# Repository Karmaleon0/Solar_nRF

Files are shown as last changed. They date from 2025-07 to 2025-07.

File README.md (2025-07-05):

A small solar-only, battery-free device that harvests energy using a single BPW34 cell, boosted and managing energy with the TI B5504.

B5504

Sending BLE advertisements every few seconds in direct sunlight - measuring the temperature using an exteral I2C digital chip connected to a Raytac nRF module.

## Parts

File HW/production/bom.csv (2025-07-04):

Designator | Footprint | Quantity | Value | LCSC Part #
C1, C2 | 0805 | 2 | 4.7u
C12, C13 | 0603 | 2 | 12p
C14 | 0805 | 1 | 100n
C3 | 0603 | 1 | 10n
C4, C6, C7, C8, C9 | 1206 | 5 | 100u
C5 | 1206 | 1 | 100uF
D1 | D_SOD-123F | 1 | 3V8
D11 | 0805 | 1 | LED
J10, J11, J4, J5 | PinSocket_1x02_P2.54mm_Vertical | 4 | Conn_01x02
J13 | PinHeader_2x03_P2.54mm_Vertical | 1 | Conn_02x03_Odd_Even
J2, J6, J7 | PinHeader_1x04_P2.54mm_Vertical | 3 | Conn_01x04
L2 | WE-TPC_2828 | 1 | WE-TPC_2828
Q1, Q2 | SOT-23 | 2 | IRLML6402
R1, R2, R4 | 0603 | 3 | R
R3, R6 | 0603 | 2 | 0R
R5, R7 | 0603 | 2 | 1M
R8 | 0805 | 1 | R
ROK_2 | 0603 | 1 | 6.49M
ROK_3 | 0603 | 1 | 6.0M
ROV_1 | 0603 | 1 | 3.16M
RUV_2 | 0603 | 1 | 1.78M
R_OC1 | 0603 | 1 | 4.99M
R_OC2 | 0603 | 1 | 15M
R_OK1 | 0603 | 1 | 3.4M
R_OV2 | 0603 | 1 | 6.19M
R_UV1 | 0603 | 1 | 4.87M
SC1 | CAPPRD508W154D1200H850 | 1 | 100mF
TC1, TC2 | TC2030-IDC | 2 | TC2030-IDC
TP1 | TestPoint_Pad_D1.0mm | 1 | TestPoint
U1 | VQFN-16-1EP_3x3mm_P0.5mm_EP1.68x1.68mm | 1 | BQ25504
U2 | SOIC-8_3.9x4.9mm_P1.27mm | 1 | ATtiny402-SS
U3 | MDBT42TV-P | 1 | MDBT42TV
U4 | SOT-563 | 1 | TMP112xxDRL
Y1 | XTAL_ABS07-32.768KHZ-T | 1 | ABS07-32.768KHZ-T

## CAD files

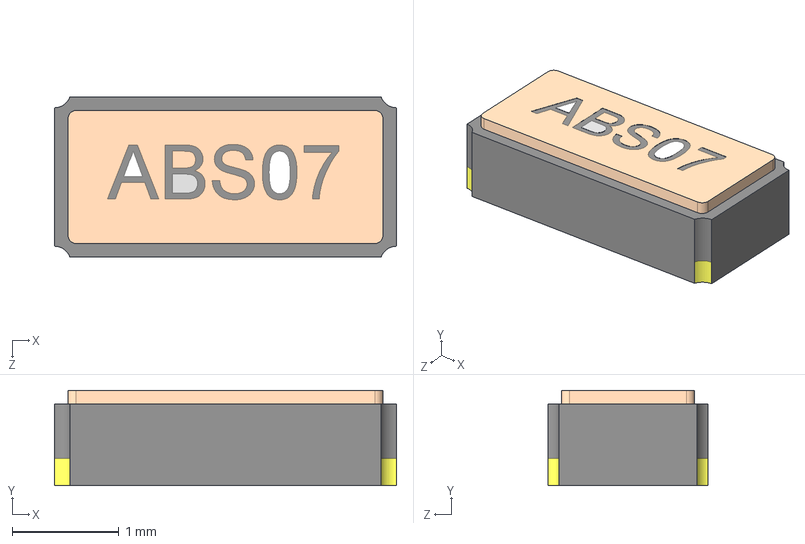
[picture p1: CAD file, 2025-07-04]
HW/Components/ABS07-32.768KHZ-T/ABS07-32.768KHZ-T.step
3.20 x 0.889 x 1.50 mm

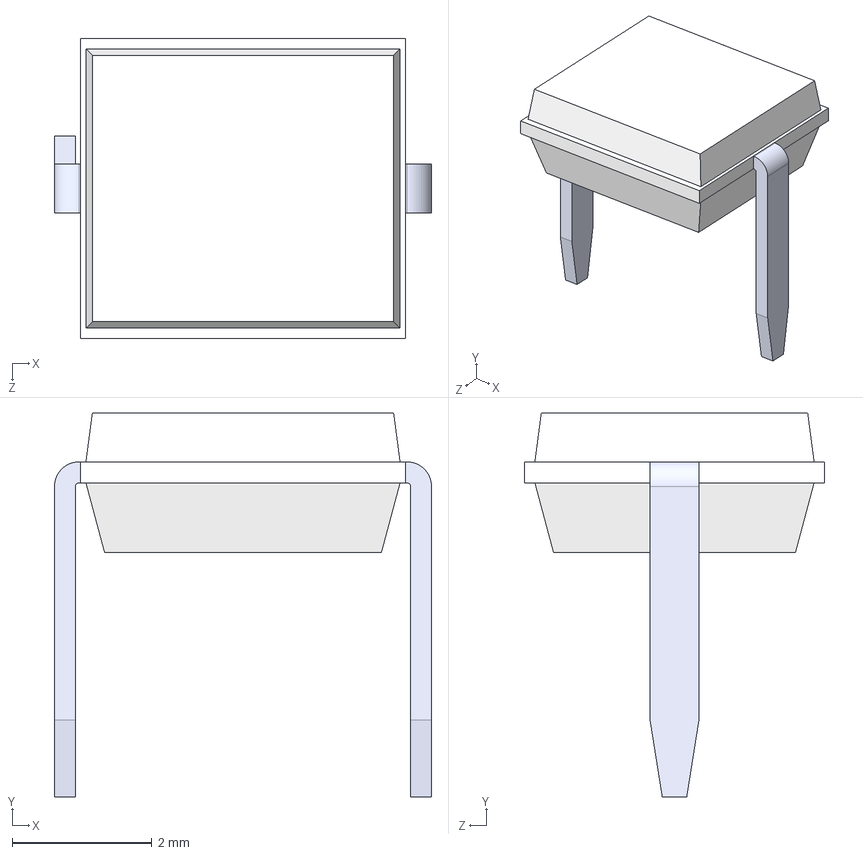
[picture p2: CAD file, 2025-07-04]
HW/Components/BPW34/BPW34--3DModel-STEP-56544.STEP
5.40 x 5.50 x 4.30 mm

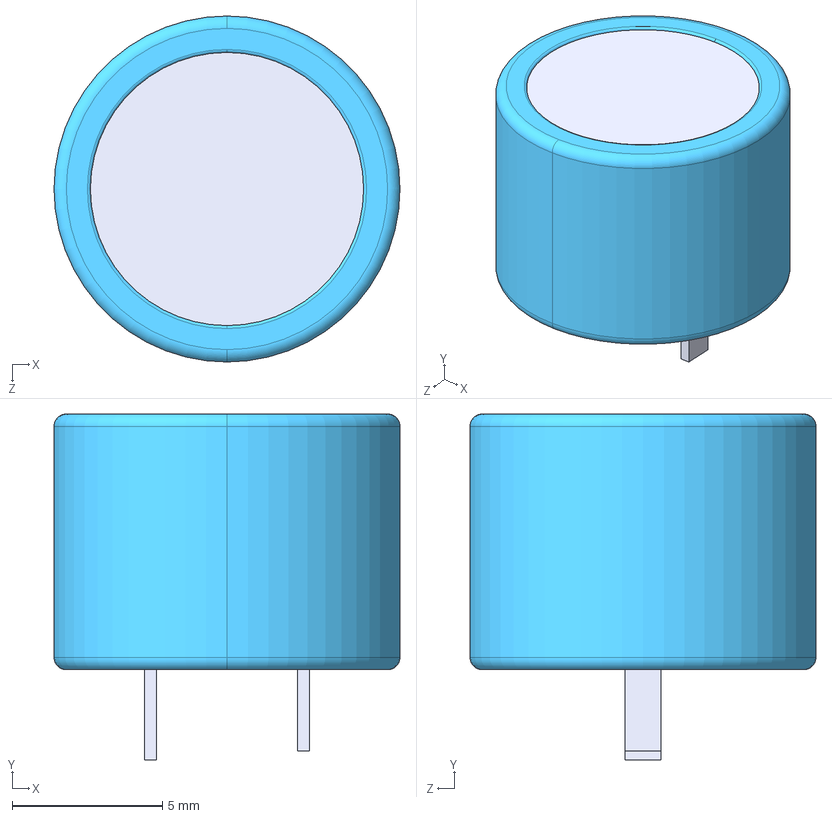
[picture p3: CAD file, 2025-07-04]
HW/Components/FT0H104ZF/FT0H104ZF.step
11.5 x 11.5 x 11.5 mm

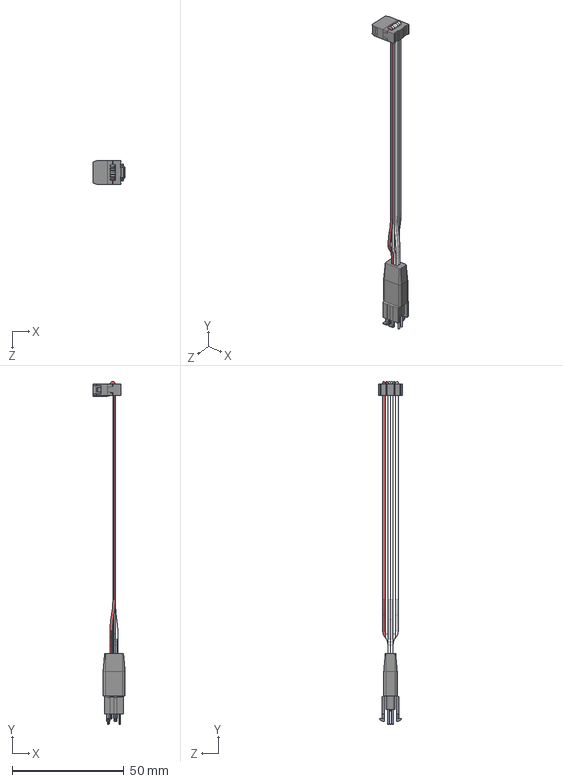
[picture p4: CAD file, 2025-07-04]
HW/Components/TC2030-IDC/TC2030-IDC.step
14.5 x 153.6 x 10.7 mm

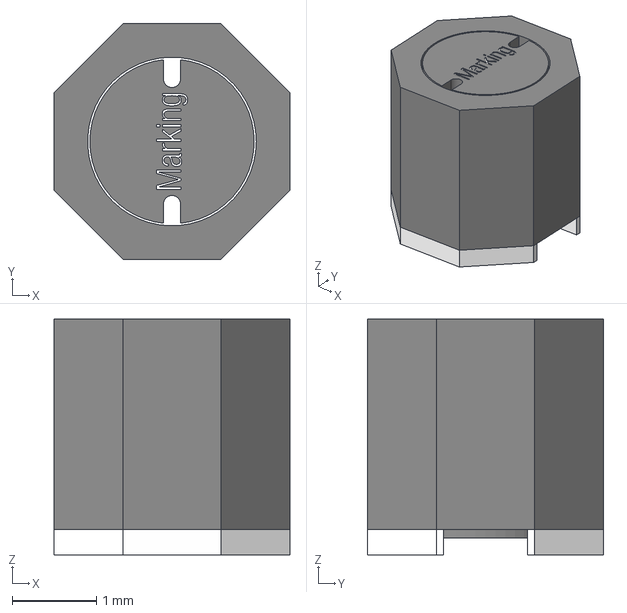
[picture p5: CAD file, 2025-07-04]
HW/Components/WE-TPC_2828.step
2.80 x 2.80 x 2.80 mm

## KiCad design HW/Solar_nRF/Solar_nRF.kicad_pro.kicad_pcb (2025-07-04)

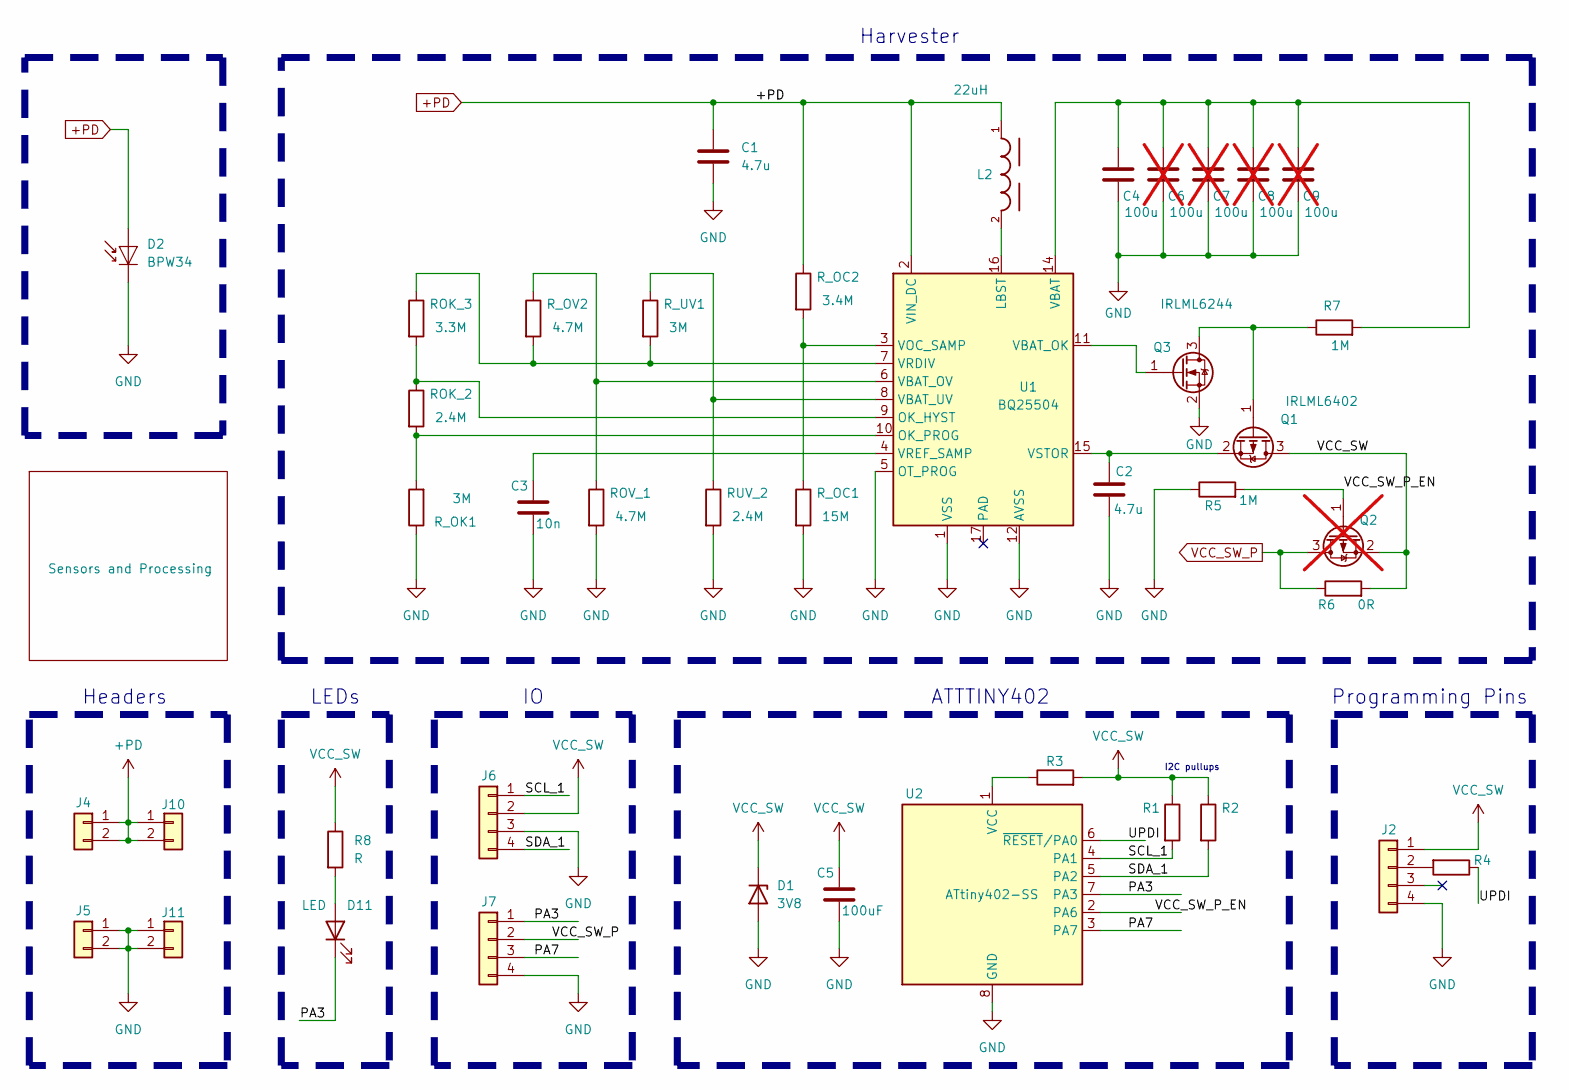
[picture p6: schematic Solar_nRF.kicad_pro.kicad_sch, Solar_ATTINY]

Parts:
C1, C2: 4.7u; C_0805_2012Metric_Pad1.18x1.45mm_HandSolder
C3: 10n; C_0603_1608Metric_Pad1.08x0.95mm_HandSolder
C4: 100u; C_1206_3216Metric_Pad1.33x1.80mm_HandSolder
C5: 100uF; C_1206_3216Metric_Pad1.33x1.80mm_HandSolder
C6, C7, C8, C9: 100u; C_1206_3216Metric_Pad1.33x1.80mm_HandSolder; not fitted
D1: 3V8; D_SOD-123F
D2: BPW34; Osram_DIL2_4.3x4.65mm_P5.08mm
D11: LED; LED_0805_2012Metric_Pad1.15x1.40mm_HandSolder
J2, J6, J7: Conn_01x04; PinHeader_1x04_P2.54mm_Vertical
J4, J5, J10, J11: Conn_01x02; PinSocket_1x02_P2.54mm_Vertical
L2: 22uH; WE-TPC_2828
Q1: IRLML6402; SOT-23
Q2: IRLML6402; SOT-23; not fitted
Q3: IRLML6244; SOT-23
R1, R2, R4: R; R_0603_1608Metric_Pad0.98x0.95mm_HandSolder
R3, R6: 0R; R_0603_1608Metric_Pad0.98x0.95mm_HandSolder
R5, R7: 1M; R_0603_1608Metric_Pad0.98x0.95mm_HandSolder
R8: R; R_0805_2012Metric_Pad1.20x1.40mm_HandSolder
ROK_2: 2.4M; R_0603_1608Metric_Pad0.98x0.95mm_HandSolder
ROK_3: 3.3M; R_0603_1608Metric_Pad0.98x0.95mm_HandSolder
ROV_1: 4.7M; R_0603_1608Metric_Pad0.98x0.95mm_HandSolder
RUV_2: 2.4M; R_0603_1608Metric_Pad0.98x0.95mm_HandSolder
R_OC1: 15M; R_0603_1608Metric_Pad0.98x0.95mm_HandSolder
R_OC2: 3.4M; R_0603_1608Metric_Pad0.98x0.95mm_HandSolder
R_OK1: 3M; R_0603_1608Metric_Pad0.98x0.95mm_HandSolder
R_OV2: 4.7M; R_0603_1608Metric_Pad0.98x0.95mm_HandSolder
R_UV1: 3M; R_0603_1608Metric_Pad0.98x0.95mm_HandSolder
U1: BQ25504; VQFN-16-1EP_3x3mm_P0.5mm_EP1.68x1.68mm
U2: ATtiny402-SS; SOIC-8_3.9x4.9mm_P1.27mm

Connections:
+PD: C1.1, D2.2 (A), J4.1, J4.2, J10.1, J10.2, L2.1, R_OC2.1, U1.2 (VIN_DC); also elsewhere on the board
/PA3: D11.1 (K), J7.1, U2.7 (PA3)
/PA7: J7.3, U2.3 (PA7)
/SCL_1: J6.1, R1.2, U2.4 (PA1)
/SDA_1: J6.4, R2.2, U2.5 (PA2)
/UPDI: R4.1, U2.6 (~RESET/PA0)
/VCC_SW_P_EN: Q2.1 (G), R5.2, U2.2 (PA6)
GND: C1.2, C2.2, C3.1, C4.2, C5.1, C6.2, C7.2, C8.2, C9.2, D1.2 (A), D2.1 (K), J2.4, J5.1, J5.2, J6.3, J7.4, J11.1, J11.2, Q3.2 (S), R5.1, ROV_1.2, RUV_2.2, R_OC1.2, R_OK1.1, U1.1 (VSS), U1.5 (OT_PROG), U1.12 (AVSS), U1.13 (VSS), U2.8 (GND); also elsewhere on the board
unnamed: D11.2 (A), R8.2
unnamed: J2.2, R4.2
unnamed: Q1.1 (G), Q3.3 (D), R7.1
unnamed: C2.1, Q1.2 (S), U1.15 (VSTOR)
unnamed: Q3.1 (G), U1.11 (VBAT_OK)
unnamed: L2.2, U1.16 (LBST)
unnamed: ROK_2.1, ROK_3.2, U1.9 (OK_HYST)
unnamed: ROK_2.2, R_OK1.2, U1.10 (OK_PROG)
unnamed: C4.1, C6.1, C7.1, C8.1, C9.1, R7.2, U1.14 (VBAT)
unnamed: ROV_1.1, R_OV2.1, U1.6 (VBAT_OV)
unnamed: RUV_2.1, R_UV1.1, U1.8 (VBAT_UV)
unnamed: R_OC1.1, R_OC2.2, U1.3 (VOC_SAMP)
unnamed: ROK_3.1, R_OV2.2, R_UV1.2, U1.7 (VRDIV)
unnamed: C3.2, U1.4 (VREF_SAMP)
unnamed: R3.1, U2.1 (VCC)
VCC_SW: C5.2, D1.1 (K), J2.1, J6.2, Q1.3 (D), Q2.2 (S), R1.1, R2.1, R3.2, R6.2, R8.1
VCC_SW_P: J7.2, Q2.3 (D), R6.1; also elsewhere on the board

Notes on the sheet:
Programming Pins
I2C pullups
ATTTINY402
Harvester
Headers
LEDs

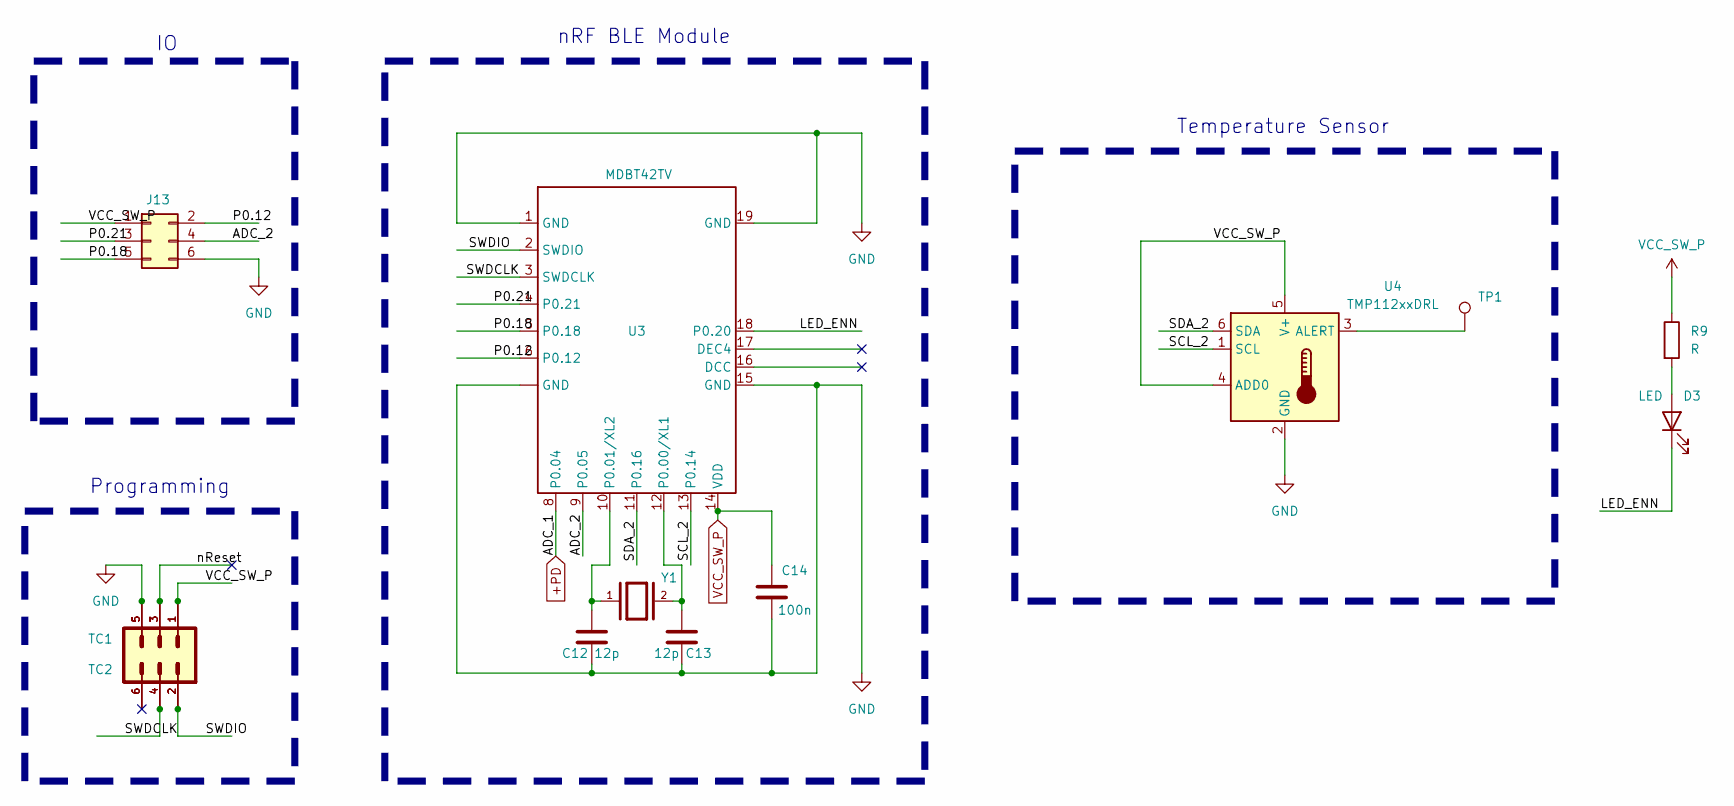
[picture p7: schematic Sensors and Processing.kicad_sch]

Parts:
C12, C13: 12p; C_0603_1608Metric_Pad1.08x0.95mm_HandSolder
C14: 100n; C_0805_2012Metric_Pad1.18x1.45mm_HandSolder
D3: LED; LED_0805_2012Metric_Pad1.15x1.40mm_HandSolder
J13: Conn_02x03_Odd_Even; PinHeader_2x03_P2.54mm_Vertical
R9: R; R_0805_2012Metric_Pad1.20x1.40mm_HandSolder
TC1, TC2: TC2030-IDC
TP1: TestPoint; TestPoint_Pad_D1.0mm
U3: MDBT42TV; MDBT42TV-P
U4: TMP112xxDRL; SOT-563
Y1: ABS07-32.768KHZ-T; XTAL_ABS07-32.768KHZ-T; PARTREV 08.19.15

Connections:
+PD: U3.8 (P0.04); also elsewhere on the board
/Sensors and Processing/ADC_2: J13.4, U3.9 (P0.05)
/Sensors and Processing/LED_ENN: D3.1 (K), U3.18 (P0.20)
/Sensors and Processing/P0.12: J13.2, U3.6 (P0.12)
/Sensors and Processing/P0.18: J13.5, U3.5 (P0.18)
/Sensors and Processing/P0.21: J13.3, U3.4 (P0.21)
/Sensors and Processing/SCL_2: U3.13 (P0.14), U4.1 (SCL)
/Sensors and Processing/SDA_2: U3.11 (P0.16), U4.6 (SDA)
/Sensors and Processing/SWDCLK: TC1.4, TC2.4, U3.3 (SWDCLK)
/Sensors and Processing/SWDIO: TC1.2, TC2.2, U3.2 (SWDIO)
/Sensors and Processing/nReset: TC1.3, TC2.3
GND: C12.1, C13.1, C14.2, J13.6, TC1.5, TC2.5, U3. (GND), U3.1 (GND), U3.15 (GND), U3.19 (GND), U4.2 (GND); also elsewhere on the board
unnamed: D3.2 (A), R9.2
unnamed: C13.2, U3.12 (P0.00/XL1), Y1.2
unnamed: C12.2, U3.10 (P0.01/XL2), Y1.1
unnamed: TP1.1, U4.3 (ALERT)
VCC_SW_P: C14.1, J13.1, R9.1, TC1.1, TC2.1, U3.14 (VDD), U4.4 (ADD0), U4.5 (V+); also elsewhere on the board

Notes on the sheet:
Programming
nRF BLE Module
Temperature Sensor

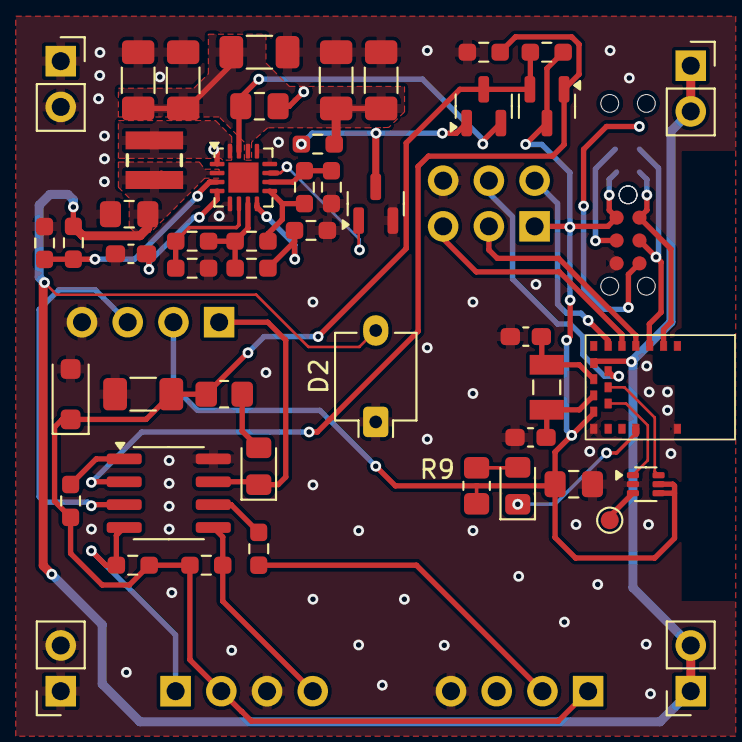
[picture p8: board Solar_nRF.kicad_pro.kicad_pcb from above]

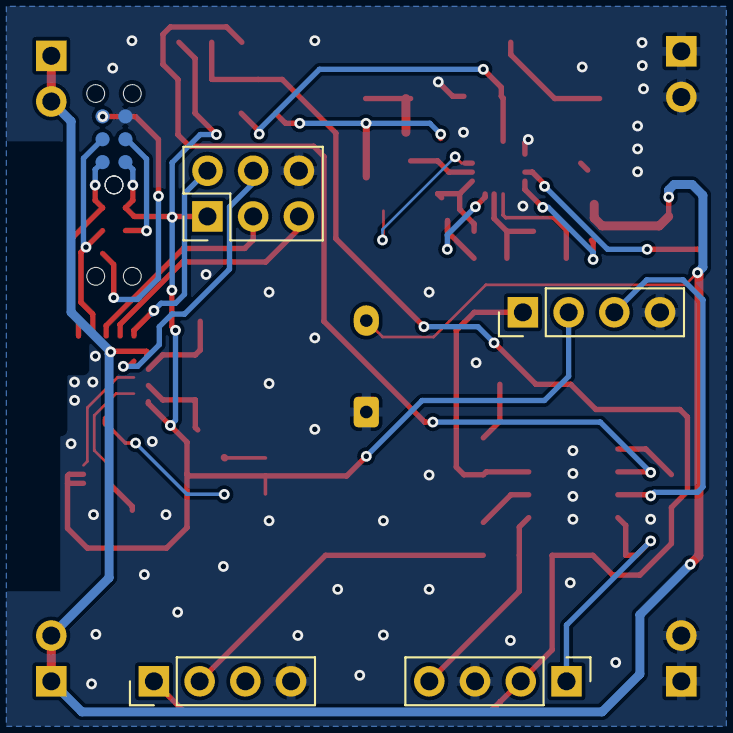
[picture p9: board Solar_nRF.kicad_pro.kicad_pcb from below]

Board: 2 copper layers, 54 parts (5 on the bottom side), 39 nets.

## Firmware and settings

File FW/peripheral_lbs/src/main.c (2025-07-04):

/*
 * Copyright (c) 2018 Nordic Semiconductor ASA
 *
 * SPDX-License-Identifier: LicenseRef-Nordic-5-Clause
 */

#include <zephyr/types.h>
#include <stddef.h>
#include <string.h>
#include <math.h>

#include <zephyr/sys/printk.h>
#include <zephyr/sys/byteorder.h>
#include <zephyr/kernel.h>
#include <zephyr/drivers/gpio.h>
#include <zephyr/drivers/sensor.h>

#include <zephyr/bluetooth/bluetooth.h>
#include <zephyr/bluetooth/hci.h>
#include <zephyr/bluetooth/conn.h>
#include <zephyr/bluetooth/gatt.h>
#include <bluetooth/services/lbs.h>      

#define DEVICE_NAME             CONFIG_BT_DEVICE_NAME

static struct bt_data ad[3];    // Advertising data array

static const struct bt_data sd[] = {
    BT_DATA_BYTES(BT_DATA_UUID128_ALL, BT_UUID_LBS_VAL),
};

int16_t temp_value = 0;     // 16-bit signed integer for temperature * 100
 
struct sensor_value temp_val;   // Zephyr sensor API structure to receive raw TMP112 output (int part and fraction part)
const struct device *temp_dev;  // Device pointer for the TMP112 sensor

// Bluetooth advertising parameters:
static const struct bt_le_adv_param adv_param = {
    .options = BT_LE_ADV_OPT_CONN,
    .interval_min = BT_GAP_ADV_FAST_INT_MIN_1,
    .interval_max = BT_GAP_ADV_FAST_INT_MAX_1,
};

void build_advertisement(void)
{
    static uint8_t mfg_data[4];

    mfg_data[0] = 0x59;          // Nordic Company ID LSB
    mfg_data[1] = 0x00;          // Nordic Company ID MSB
    mfg_data[2] = temp_value & 0xFF;
    mfg_data[3] = (temp_value >> 8) & 0xFF;

    ad[0] = (struct bt_data)BT_DATA_BYTES(BT_DATA_FLAGS, (BT_LE_AD_GENERAL | BT_LE_AD_NO_BREDR));
    ad[1] = (struct bt_data)BT_DATA(BT_DATA_NAME_COMPLETE, DEVICE_NAME, sizeof(DEVICE_NAME) - 1);
    ad[2] = (struct bt_data)BT_DATA(BT_DATA_MANUFACTURER_DATA, mfg_data, sizeof(mfg_data));
}

int main(void)
{
    int err;

    temp_dev = device_get_binding("TMP112");
    k_sleep(K_MSEC(100));  // Wait 100ms to allow sensor startup

    if (!temp_dev) {
        printk("TMP112 not found!\n");
        return 0;
    }

    if (sensor_sample_fetch(temp_dev) == 0 &&
        sensor_channel_get(temp_dev, SENSOR_CHAN_AMBIENT_TEMP, &temp_val) == 0) {
        float temperature = sensor_value_to_double(&temp_val);
        temp_value = (int16_t)roundf(temperature * 100.0f);
        printk("Temperature read: %d\n", temp_value);
    } else {
        printk("Sensor fetch failed\n");
        return 0;
    }

    build_advertisement();

    err = bt_enable(NULL);
    if (err) {
        printk("Bluetooth init failed (err %d)\n", err);
        return 0;
    }

    err = bt_le_adv_start(&adv_param, ad, ARRAY_SIZE(ad), sd, ARRAY_SIZE(sd));
    if (err) {
        printk("Advertising start failed (err %d)\n", err);
        return 0;
    }

    printk("Advertising started with temp value\n");

    while (1) {
        k_sleep(K_FOREVER);
    }
}

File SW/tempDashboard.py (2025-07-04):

import sys
import re
import time
import csv
from datetime import datetime
from PyQt6.QtWidgets import (
    QApplication, QLabel, QWidget, QVBoxLayout, QGraphicsDropShadowEffect
)
from PyQt6.QtCore import QTimer, QThread, pyqtSignal, Qt
from PyQt6.QtGui import QFont, QColor
import serial
from datetime import datetime
import serial.tools.list_ports

## COM_PORT = 'COM4'  # Change as needed
BAUD_RATE = 115200

import serial.tools.list_ports  # Add to your imports

class SerialReaderThread(QThread):
    data_received = pyqtSignal(str, float, int, float)  # name, temp, rssi, timestamp

    def __init__(self):
        super().__init__()
        self.running = True
        self.ser = None

        # Look for J-Link port
        ports = list(serial.tools.list_ports.comports())
        for port in ports:
            if "JLink" in port.description:
                try:
                    self.ser = serial.Serial(port.device, BAUD_RATE, timeout=1)
                    print(f"Connected to {port.device} ({port.description})")
                    break
                except Exception as e:
                    print(f"Error opening {port.device}: {e}")

        if not self.ser:
            print("No J-Link COM port found.")


    def run(self):
        if not self.ser:
            return

        while self.running:
            line = self.ser.readline().decode(errors='ignore').strip()
            match = re.search(r'Temp from (.+?): (\-?\d+\.\d{2}) C \(RSSI (-?\d+)\)', line)
            if match:
                name = match.group(1)
                temp = float(match.group(2))
                timestamp = time.time()
                rssi = int(match.group(3))
                self.data_received.emit(name, temp, rssi, timestamp)

    def stop(self):
        self.running = False
        self.wait()

def add_glow(label: QLabel, color_hex: str, radius=20, strength=0.9):
    glow = QGraphicsDropShadowEffect()
    glow.setBlurRadius(radius)
    glow.setColor(QColor(color_hex))
    glow.setOffset(0, 0)
    label.setGraphicsEffect(glow)

class TempDashboard(QWidget):
    def __init__(self):
        super().__init__()

        self.last_time = time.time()  # initialize to now, so elapsed time starts counting
        now_str = datetime.now().strftime("%Y-%m-%d_%H-%M-%S")
        filename = f"temperature_log_{now_str}.csv"

        self.setWindowTitle("tempDashboard")
        self.setGeometry(300, 300, 450, 220)

        # Fonts
        self.temp_font = QFont("Segoe UI", 120, QFont.Weight.Bold)
        self.info_font = QFont("Segoe UI", 60)

        # Layout
        layout = QVBoxLayout()
        layout.setContentsMargins(40, 40, 40, 40)
        layout.setSpacing(20)

        # Temp label (big neon number)
        self.temp_label = QLabel("")
        self.temp_label.setFont(self.temp_font)
        self.temp_label.setAlignment(Qt.AlignmentFlag.AlignCenter)

        # Elapsed time label
        self.elapsed_label = QLabel("")
        self.elapsed_label.setFont(self.info_font)
        self.elapsed_label.setAlignment(Qt.AlignmentFlag.AlignCenter)
        self.elapsed_label.setStyleSheet("color: #FF69B4;")  # Hot Pink neon text
        add_glow(self.elapsed_label, "#FF69B4", radius=25)

        # RSSI label
        self.rssi_label = QLabel("")
        self.rssi_label.setFont(self.info_font)
        self.rssi_label.setAlignment(Qt.AlignmentFlag.AlignCenter)
        self.rssi_label.setStyleSheet("color: #FF69B4;")  # Hot Pink neon text
        add_glow(self.rssi_label, "#FF69B4", radius=25)

        # ... after creating labels:

        self.temp_label = QLabel("")
        self.temp_label.setFont(self.temp_font)
        self.temp_label.setAlignment(Qt.AlignmentFlag.AlignCenter)
        self.temp_label.setText("0.00 °C")
        self.temp_label.setStyleSheet("color: #00FFFF;")
        add_glow(self.temp_label, "#00FFFF", radius=40)

        self.elapsed_label = QLabel("")
        self.elapsed_label.setFont(self.info_font)
        self.elapsed_label.setAlignment(Qt.AlignmentFlag.AlignCenter)
        self.elapsed_label.setText("No data received yet")
        self.elapsed_label.setStyleSheet("color: #FF69B4;")
        add_glow(self.elapsed_label, "#FF69B4", radius=25)

        self.rssi_label = QLabel("")
        self.rssi_label.setFont(self.info_font)
        self.rssi_label.setAlignment(Qt.AlignmentFlag.AlignCenter)
        self.rssi_label.setText("RSSI: N/A")
        self.rssi_label.setStyleSheet("color: #FF69B4;")
        add_glow(self.rssi_label, "#FF69B4", radius=25)


        layout.addWidget(self.temp_label)
        layout.addWidget(self.elapsed_label)
        layout.addWidget(self.rssi_label)

        self.setLayout(layout)

        # Dark background
        self.setStyleSheet("""
            QWidget {
                background-color: #0f0f1a;
                border-radius: 20px;
            }
            QLabel {
                padding: 5px;
            }
        """)

        self.serial_thread = SerialReaderThread()
        self.serial_thread.data_received.connect(self.update_data)
        self.serial_thread.start()

        self.timer = QTimer()
        self.timer.timeout.connect(self.update_elapsed)
        self.timer.start(1000)

        self.csv_file = open(filename, "a", newline="")
        self.csv_writer = csv.writer(self.csv_file)
        if self.csv_file.tell() == 0:
            self.csv_writer.writerow(["Timestamp", "Name", "Temperature", "RSSI"])

    def update_data(self, name, temp, rssi, timestamp):
        neon_cyan = "#00FFFF"
        self.temp_label.setText(f"{temp:.2f} °C")
        self.temp_label.setStyleSheet(f"color: {neon_cyan};")
        add_glow(self.temp_label, neon_cyan, radius=40)

        self.rssi_label.setText(f"RSSI: {rssi} dBm")

        self.last_time = timestamp

        dt = datetime.fromtimestamp(timestamp).strftime('%Y-%m-%d %H:%M:%S')
        self.csv_writer.writerow([dt, name, f"{temp:.2f}", rssi])
        self.csv_file.flush()

    def update_elapsed(self):
        if self.last_time is None:
            self.elapsed_label.setText("No data received yet")
        else:
            elapsed = time.time() - self.last_time
            self.elapsed_label.setText(f"Last update: {int(elapsed)}s ago")

    def closeEvent(self, event):
        self.serial_thread.stop()
        self.csv_file.close()
        event.accept()

if __name__ == "__main__":
    app = QApplication(sys.argv)
    window = TempDashboard()
    window.show()
    sys.exit(app.exec())

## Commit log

2025-07-04 Upload for youtube
    [ABS07-32.768KHZ-T.step, BPW34--3DModel-STEP-56544.STEP, FT0H104ZF.step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]
2025-07-04 Updated SCH & PCB based with fixes found during development
    Inverted bat_ok signal
    Cleaned up layout, removing solar array and replacing with a single photodiode
    Connected nRF to +V programming pad
    [Sensors and Processing.kicad_sch, Solar_nRF.kicad_pro.kicad_pcb, Solar_nRF.kicad_pro.kicad_sch]
